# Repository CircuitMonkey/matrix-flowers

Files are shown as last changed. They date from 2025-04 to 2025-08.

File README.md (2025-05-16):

# matrix-flowers
Electronic art project. Vase of flowers made with seven segment LED modules.

* Matrix Flower 1
A flower made with module found on Amazon. See my proof of concept project
for the 74HC164 based module on Arduino at:
https://github.com/CircuitMonkey/hc164-2x4-led-segment-module

<p align="center">
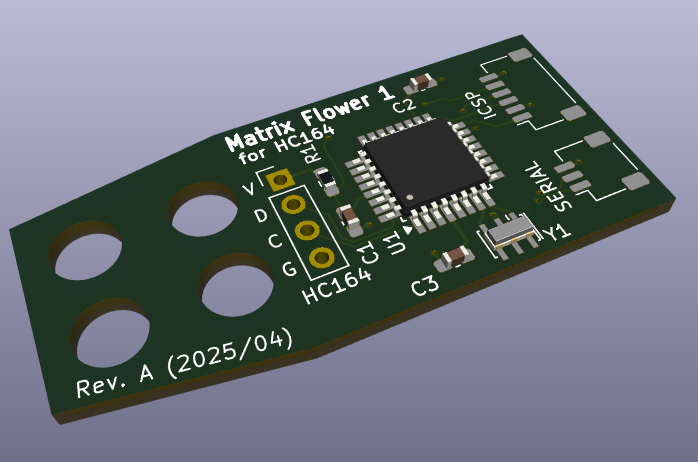
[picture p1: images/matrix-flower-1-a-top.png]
PCB Top View
  
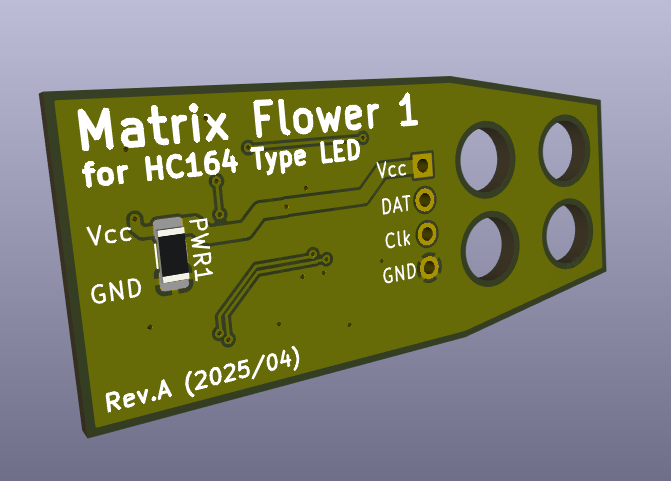
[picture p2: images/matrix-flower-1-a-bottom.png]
PCB Bottom View
  
</p>

This flower project builds upon the proof-of-concept by making a custom
barebones Arduino PCB using the ATmega328P and allows direct soldering of the
LED modulel to that board. The board also provides mechanical mounting of a
fabricated flower stem that facilitates DC power to the module from the bottom
of the powered vase.

[YouTube: Video of the working bouquet for Matrix-1](https://youtu.be/2mtg5pHPPw4)

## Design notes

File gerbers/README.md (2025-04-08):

# matrix-flowers gerbers of previously fabbed PCBs.

Gerber files for my electronic art project. A vase of flowers made with seven segment LED modules.

Here you will find zip files containing the gerbers needed to make that
model and revision at a place like OshPark.com. Just upload the zip.

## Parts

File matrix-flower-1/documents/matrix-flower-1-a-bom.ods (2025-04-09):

Matrix Flower 1 (rev. A 2025/04) – Bill of Materials
Reference | Value | Footprint | Datasheet | Qty | DNP | Exclude from BOM | Exclude from Board
C1,C2,C3 | 0.1uF | Capacitor_SMD:C_0603_1608Metric_Pad1.08x0.95mm_HandSolder | ~ | 3
HC164 | Conn_01x04_Pin | Connector_PinHeader_2.54mm:PinHeader_1x04_P2.54mm_Vertical | ~ | 1
ICSP1 | JST-SH-SM06 | Connector_JST:JST_SH_SM06B-SRSS-TB_1x06-1MP_P1.00mm_Horizontal | https://www.amazon.com/dp/B0BKSNMCV4 | 1
PWR1 | NP | Resistor_SMD:R_1206_3216Metric_Pad1.30x1.75mm_HandSolder | ~ | 1 |  | YES | YES
R1 | 10K | Resistor_SMD:R_0603_1608Metric_Pad0.98x0.95mm_HandSolder | ~ | 1
SERIAL1 | JST-SH-SM03 | Connector_JST:JST_SH_SM03B-SRSS-TB_1x03-1MP_P1.00mm_Horizontal | https://www.amazon.com/dp/B09GP9S1W7 | 1
U1 | ATmega328P-A | Package_QFP:TQFP-32_7x7mm_P0.8mm | http://ww1.microchip.com/downloads/en/DeviceDoc/ATmega328_P%20AVR%20MCU%20with%20picoPower%20Technology%20Data%20Sheet%2040001984A.pdf | 1
Y1 | 16MHz Res. | Crystal:Resonator_SMD_Murata_CSTxExxV-3Pin_3.0x1.1mm_HandSoldering | ~ | 1

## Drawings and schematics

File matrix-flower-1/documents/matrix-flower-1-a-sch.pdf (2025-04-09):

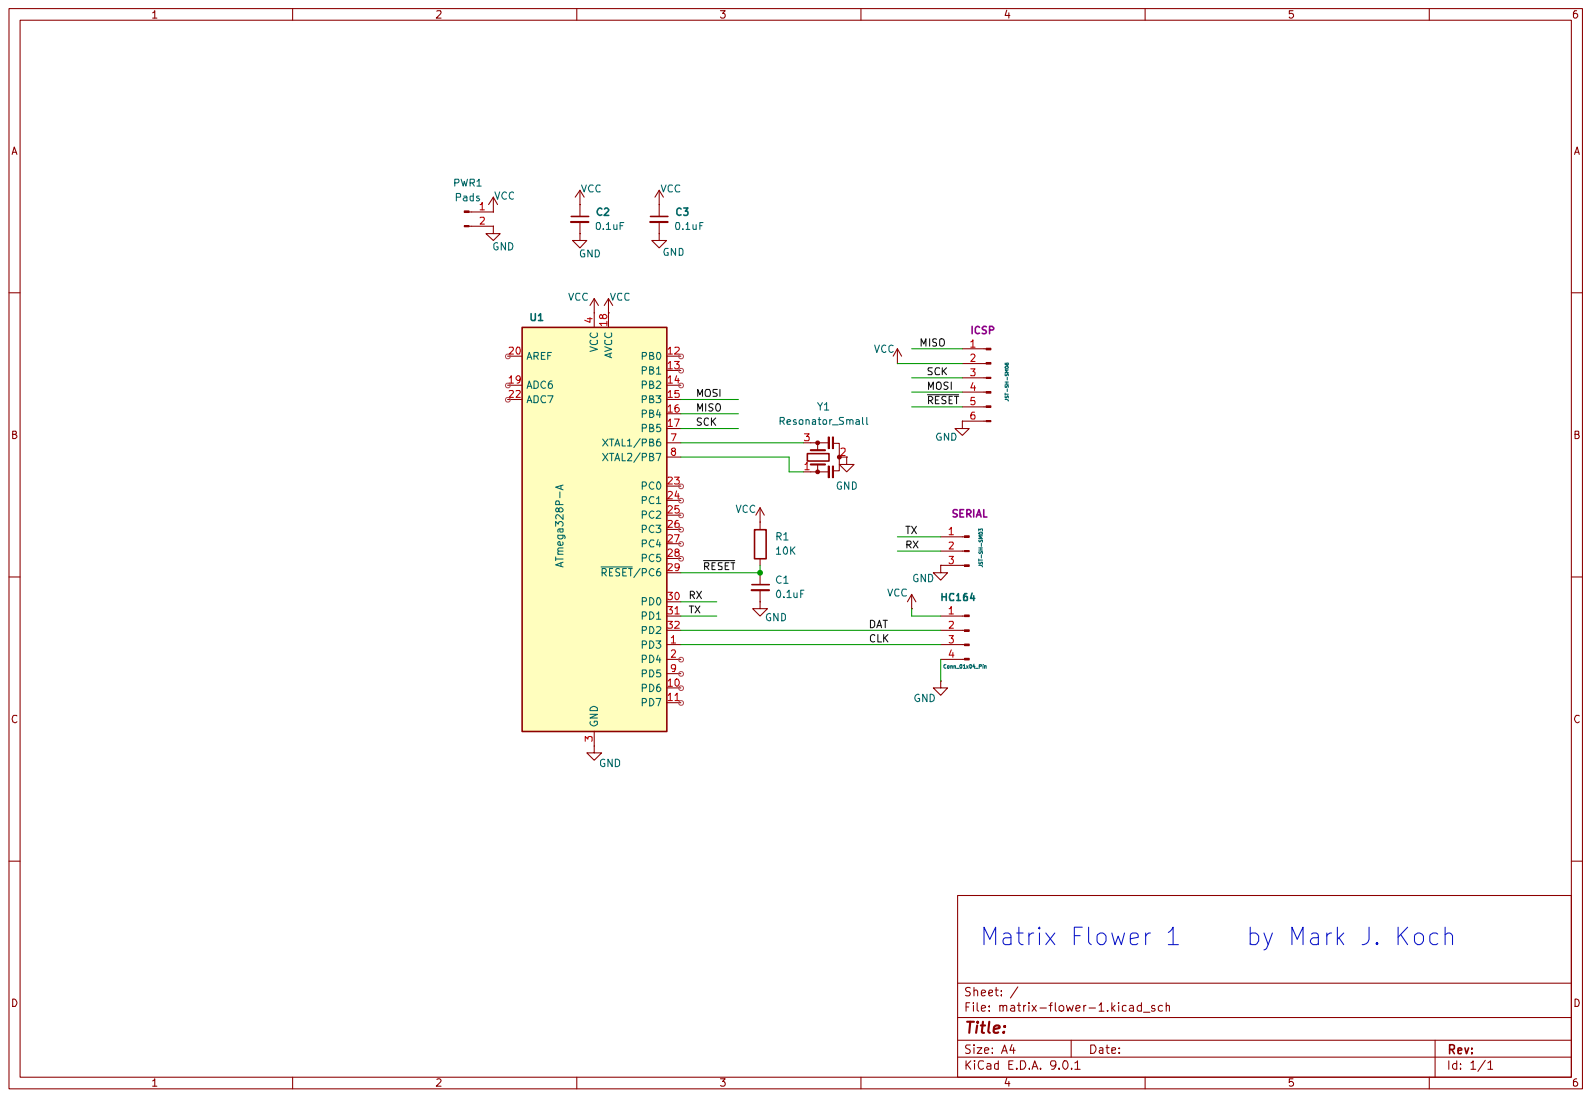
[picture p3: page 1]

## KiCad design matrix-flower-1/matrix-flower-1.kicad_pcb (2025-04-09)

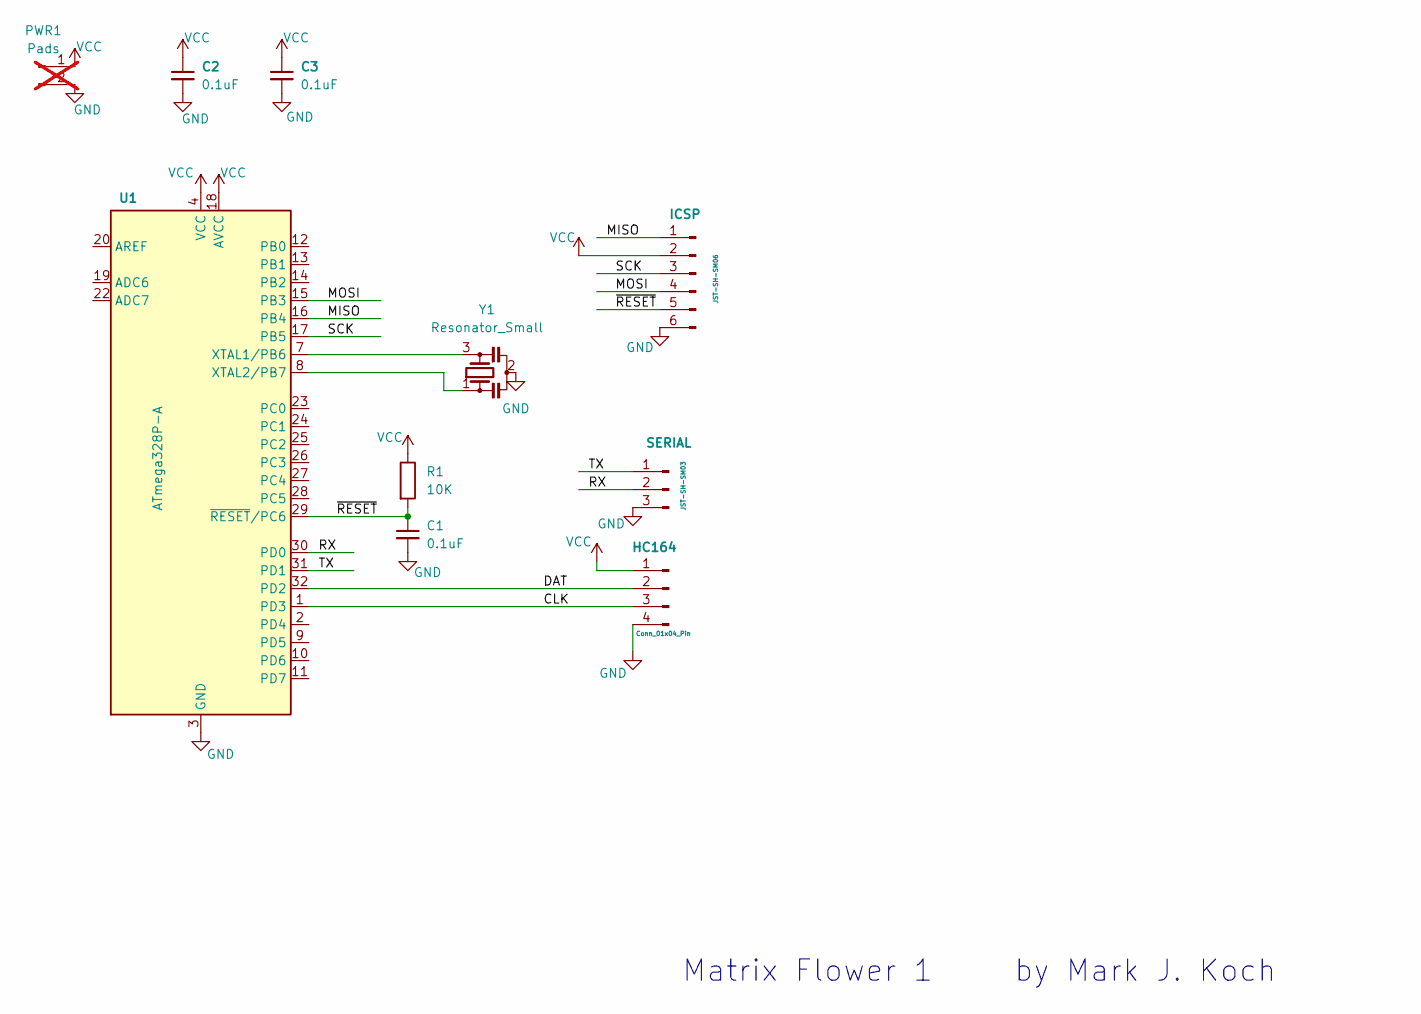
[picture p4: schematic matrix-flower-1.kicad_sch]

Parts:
C1, C2, C3: 0.1uF; C_0603_1608Metric_Pad1.08x0.95mm_HandSolder
HC164: Conn_01x04_Pin; PinHeader_1x04_P2.54mm_Vertical
ICSP1: JST-SH-SM06; JST_SH_SM06B-SRSS-TB_1x06-1MP_P1.00mm_Horizontal
PWR1: Pads; R_1206_3216Metric_Pad1.30x1.75mm_HandSolder; not fitted
R1: 10K; R_0603_1608Metric_Pad0.98x0.95mm_HandSolder
SERIAL1: JST-SH-SM03; JST_SH_SM03B-SRSS-TB_1x03-1MP_P1.00mm_Horizontal
U1: ATmega328P-A; TQFP-32_7x7mm_P0.8mm
Y1: Resonator_Small; Resonator_SMD_Murata_CSTxExxV-3Pin_3.0x1.1mm_HandSoldering

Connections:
/CLK: HC164.3, U1.1 (PD3)
/DAT: HC164.2, U1.32 (PD2)
/MISO: ICSP1.1, U1.16 (PB4)
/MOSI: ICSP1.4, U1.15 (PB3)
/RX: SERIAL1.2, U1.30 (PD0)
/SCK: ICSP1.3, U1.17 (PB5)
/TX: SERIAL1.1, U1.31 (PD1)
/~RESET: C1.1, ICSP1.5, R1.2, U1.29 (~RESET/PC6)
GND: C1.2, C2.2, C3.2, HC164.4, ICSP1.6, PWR1.2, SERIAL1.3, U1.3 (GND), U1.5 (GND), U1.21 (GND), Y1.2
unnamed: U1.7 (XTAL1/PB6), Y1.3
unnamed: U1.8 (XTAL2/PB7), Y1.1
VCC: C2.1, C3.1, HC164.1, ICSP1.2, PWR1.1, R1.1, U1.4 (VCC), U1.6 (VCC), U1.18 (AVCC)

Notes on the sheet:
Matrix Flower 1 by Mark J. Koch

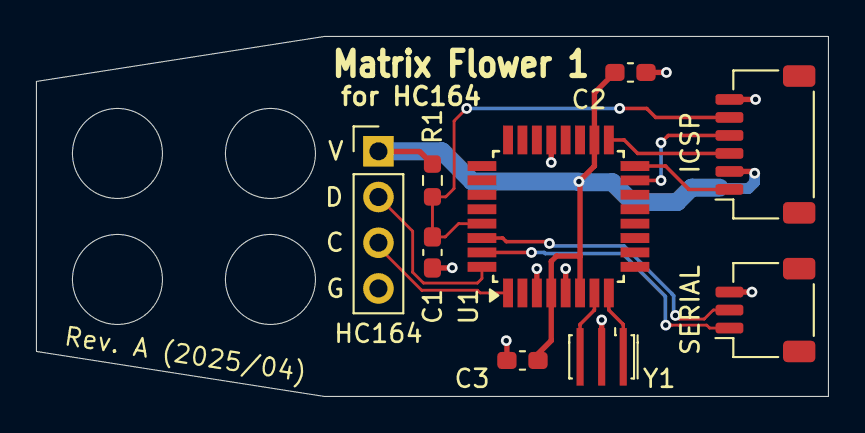
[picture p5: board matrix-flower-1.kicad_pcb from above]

Board: 2 copper layers, 44.0 x 20.0 mm, 10 parts (1 on the bottom side), 12 nets.

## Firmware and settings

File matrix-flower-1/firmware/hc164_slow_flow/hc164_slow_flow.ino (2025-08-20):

/*
  HC164 Slow Flow - for Flower 1

  by Mark J Koch ( @maehem at GitHub )

  Slow moving and random segment bits.
  
*/

#define DATA_PIN 2
#define CLK_PIN 3

// Segment layout
// Seg: MSB-LSB: 
//     7: top,
//     6: r-upper
//     5: r-lower
//     4: bot
//     3: l-lower
//     2: l-upper
//     1: mid
//     0: point 
//
// Another way to look at it: Clockwise: top..mid..point
//

uint8_t seg[8] = {
  0b00000001, // 8
  0b00011111, // 7
  0b01000001, // 6
  0b01001001, // 5
  0b10011001, // 4
  0b00001101, // 3
  0b00100101, // 2
  0b10011111  // 1

};

int val;
int val2;

void setup() {
  pinMode(DATA_PIN, OUTPUT);
  pinMode(CLK_PIN, OUTPUT);

  digitalWrite(DATA_PIN, LOW);
  digitalWrite(CLK_PIN, LOW);

  // for (int i = 0; i < 4; i++) {
  //   for (int j = 0; j < 8; j++) {
  //     digitalWrite(DATA_PIN, (seg[i] >> j) & 0x01);
  //     clkPulse();
  //   }
  // }
}

void loop() {
  int channel = 0x80;

  val = random(256) | random(256);
  val2 = random(2)?random(16):(random(16)<<4);

  for (int i = 0; i < 8; i++) {

    for (int j = 0; j < 8; j++) { // Write the segment data.
      digitalWrite(DATA_PIN, (val >> j) & 0x01);
      clkPulse();
    }
    
    for (int j = 0; j < 8; j++) { // Write which digit to address.
      digitalWrite(DATA_PIN, (val2 >> j) & 0x01);
      clkPulse();
    }

  }
}

void clkPulse() {
  digitalWrite(CLK_PIN, HIGH);
  digitalWrite(CLK_PIN, LOW);
  //delayMicroseconds(10);

  // Slow the clock for cool Matrix effect.
  delay(120);
}

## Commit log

2025-04-08 Add gerbers for matrix-flower-1-a
2025-04-08 Add KiCAD files for matrix-flower-1
    [matrix-flower-1.kicad_pcb, matrix-flower-1.kicad_sch]
2025-04-08 Update README with PCB images.
2025-04-09 Add BOM and schematic.
    [matrix-flower-1-a-bom.ods]
2025-04-09 Update component information.
    [matrix-flower-1.kicad_pcb, matrix-flower-1.kicad_sch]
